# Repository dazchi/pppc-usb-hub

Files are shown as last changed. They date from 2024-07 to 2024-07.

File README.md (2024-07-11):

# Per-port Power Control USB HUB
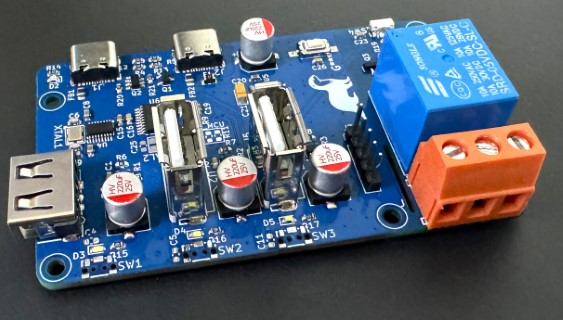
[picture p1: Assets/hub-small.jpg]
Preview


## Key Features
* 3-port USB hub fully compatiable with USB High-Speed(480Hz), Full-Speed(12Hz) and Low-Speed(1.5MHz) devices
* Supports per-port power control, current limitation and thermal shutdown protection
* No special driver required, reuses the driver from the widely known CH340 USB-to-serial chip
* Supports 5V 2A external USB-C power supply
* Reverse current protection along with resetable fuse
* Relay: SRD-05VDC-SL-C 10A 30VDC, 10A 250VAC
* Customized settings stored in built-in flash memory

## Schematic & Layout (Designed w/ KiCAD 8.0)
Schematic  
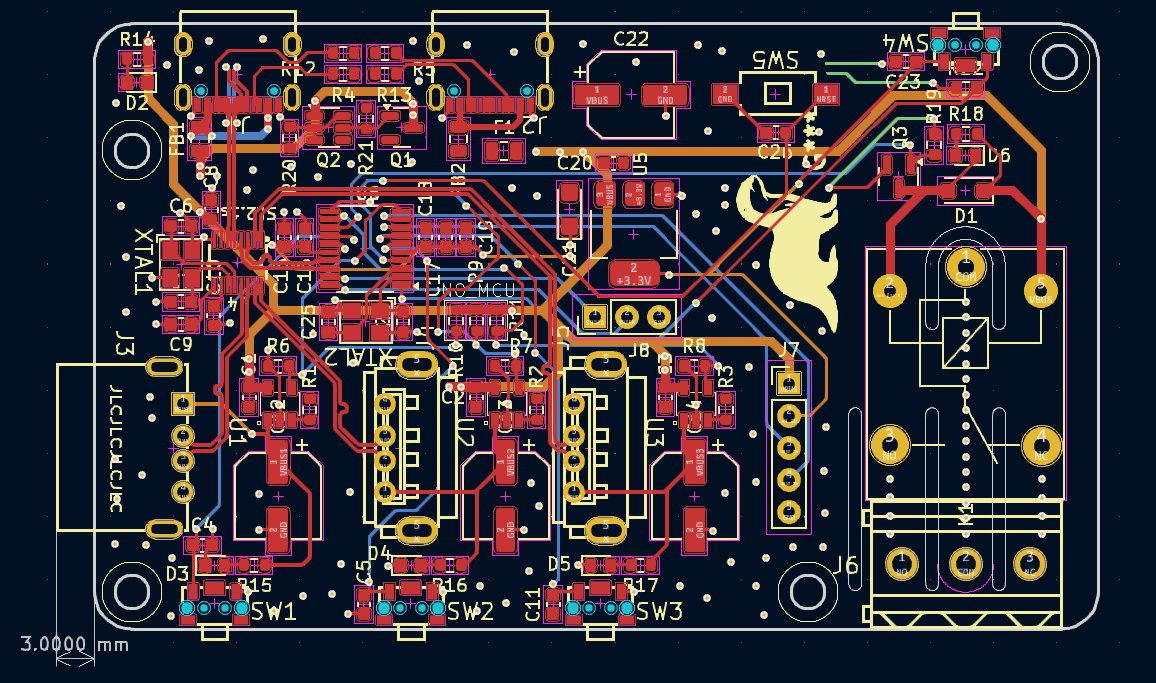
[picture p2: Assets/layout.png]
Schematic
  

## 3D Printed Case (Designed w/ Fusion 360)
3D Printed Case 

## Basic Control Commands (Group Control)
Turn On:  ```A0 01 01 A2```
  
Turn Off: ```A0 01 00 A1```
  
*These commands are designed to mimic the command of **[USB RELAY](https://www.smart-prototyping.com/USB-Relay-1-Channel)** on purpose*  
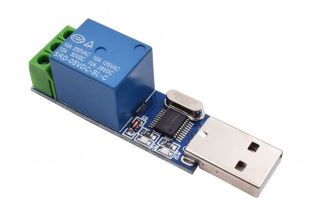
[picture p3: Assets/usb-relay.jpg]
USB RELAY
  

## Advanced Control Commands

### Per-port control
Foramt: ```F0 {AA} {BB} {ZZ} ```  

* ```{AA}``` Port Address:  
  | Port | Address |
  |:----:|:-------:|
  | USB1 |   0x01  |
  | USB2 |   0x02  |
  | USB3 |   0x03  |
  | Relay|   0x04  |

*  ```{BB}``` On/Off:  
    * ON: ```0x01```  
    * OFF: ```0x00```  

* ```{ZZ}``` Checksum:  
 ```ZZ = (0xF0 + {AA} + {BB}) & 0xFF```

Example:  
* Turn on USB1: ```F0 01 01 F2```  
* Turn off Relay: ```F0 04 00 F4```  

### Write Device Settings
Format:  
* Command: ```AB CD EF 67 {X1 X2 X3 X4} ZZ```:

    *  ```{X1 X2 X3 X4}``` Device Settings:  
        |          |                       |
        |:--------:|:---------------------:|
        | ```X1``` |   USB1 Port Settings  |
        | ```X2``` |   USB2 Port Settings  |
        | ```X3``` |   USB3 Port Settings  |
        | ```X4``` |  Relay Port Settings  |
        ```c
        typedef struct DeviceSettings
        {
            PortSettings_t usb1;
            PortSettings_t usb2;
            PortSettings_t usb3;
            PortSettings_t relay;
        } __attribute__((packed)) DeviceSettings_t;
        ```
        * Port Settings:  
            |  Bit Field |  Setting  |  Description |
            |:--------:|:---------------------:|:------------------|
            | b0 |   Port Default State  | Default state of port while power on  |
            | b1 |   *Group Control       | 0: Disable group control (ignores **Basic Control Commands**)<br>1: Enable group control
            | b2 |   *Polarity  | Polarity of the port during group control<br>0: Default polarity<br>1: Reversed polarity
            | b3 ~ b7 |  Reserved  |  Reserved for future use   |

            **The **Group Control** and the **Polarity** only affets the **Basic Control Commands***
            ```c
            typedef struct PortSettings
            {
                uint8_t defaultState :1;
                uint8_t groupControl :1;
                uint8_t polarity :1;
                uint8_t reserved :5;
            } __attribute__((packed)) PortSettings_t;
            ```
    * ```{ZZ}``` Checksum:  
    ```ZZ = (0xAB + 0xCD + 0xEF + 0x67 + {X1} {X2} {X3} {X4}) & 0xFF```

* Response:  
    ```SUCCESS``` or ```FAILED```

Example:  
* Defaut Devcie Settings  
    TX: ```AB CD EF 67 07 07 07 02 E5```  
    RX: ```SUCCESS```  

    This command sets the default state of USB1, USB2 and USB3 to On, the default state of Relay to Off.  
    The "Turn on" command ```A0 01 01 A2``` turns on the relay but turns off USB1, USB2 and USB3.  
    The "Turn off" command ```A0 01 00 A1``` turns off the relay but turns on USB1, USB2 and USB3.

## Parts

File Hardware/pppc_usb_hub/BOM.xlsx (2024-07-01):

Reference | Value | Datasheet | Footprint | Qty | DNP | MSRP | Total
C1,C2,C3,C4,C5,C11,C25 | 0.1uF | https://www.lcsc.com/product-detail/Multilayer-Ceramic-Capacitors-MLCC-SMD-SMT_Samsung-Electro-Mechanics-CL10B104KB8NNNC_C1591.html | Capacitor_SMD:C_0201_0603Metric | 7 |  | 0.0024 | 3.8712
C6,C7,C23,C24 | 20pF | https://www.lcsc.com/product-detail/Multilayer-Ceramic-Capacitors-MLCC-SMD-SMT_FH-Guangdong-Fenghua-Advanced-Tech-0603CG200F500NT_C165732.html | Capacitor_SMD:C_0201_0603Metric | 4 |  | 0.014
C8,C9,C10,C20 | 10uF | https://www.lcsc.com/product-detail/Multilayer-Ceramic-Capacitors-MLCC-SMD-SMT_Samsung-Electro-Mechanics-CL10A106MQ8NNNC_C1691.html | Capacitor_SMD:C_0201_0603Metric | 4 |  | 0.0044
C12,C13,C14,C22 | 220uF | https://www.lcsc.com/product-detail/Solid-Capacitors_Honor-Elec-HV1E227M0607PZ_C5246541.html | Capacitor_SMD:CP_Elec_6.3x7.7 | 4 |  | 0.1408
C15 | 4.7uF | https://www.lcsc.com/product-detail/Multilayer-Ceramic-Capacitors-MLCC-SMD-SMT_Samsung-Electro-Mechanics-CL10A475KQ8NNNC_C8032.html | Capacitor_SMD:C_0201_0603Metric | 1 |  | 0.0041
C16,C17 | 100nF | https://www.lcsc.com/product-detail/Multilayer-Ceramic-Capacitors-MLCC-SMD-SMT_Samsung-Electro-Mechanics-CL10B104KB8NNNC_C1591.html | Capacitor_SMD:C_0201_0603Metric | 2 |  | 0.0024
C18 | 10nF | https://www.lcsc.com/product-detail/Multilayer-Ceramic-Capacitors-MLCC-SMD-SMT_YAGEO-CC0603KRX7R9BB103_C100042.html | Capacitor_SMD:C_0201_0603Metric | 1 |  | 0.0019
C19 | 1uF | https://www.lcsc.com/product-detail/Multilayer-Ceramic-Capacitors-MLCC-SMD-SMT_Samsung-Electro-Mechanics-CL10A105KB8NNNC_C15849.html | Capacitor_SMD:C_0201_0603Metric | 1 |  | 0.0042
C21 | 22uF | https://www.lcsc.com/product-detail/Tantalum-Capacitors_KEMET-T491A226K006AT_C118989.html | Capacitor_Tantalum_SMD:CP_EIA-3216-10_Kemet-I | 1 |  | 0.0801
D1 | 1N4007 | https://www.lcsc.com/product-detail/Diodes-General-Purpose_MSKSEMI-1N4007-A7_C2902912.html | Diode_SMD:D_SOD-123F | 1 |  | 0.0038
D2 | POWER | https://www.lcsc.com/product-detail/Light-Emitting-Diodes-LED_XINGLIGHT-XL-1608UOC-06_C965800.html | LED_SMD:LED_0201_0603Metric | 1 |  | 0.0051
D3 | USB1 | https://www.lcsc.com/product-detail/Light-Emitting-Diodes-LED_XINGLIGHT-XL-1608UWC-04_C965808.html | LED_SMD:LED_0201_0603Metric | 1 |  | 0.0053
D4 | USB2 | https://www.lcsc.com/product-detail/Light-Emitting-Diodes-LED_XINGLIGHT-XL-1608UWC-04_C965808.html | LED_SMD:LED_0201_0603Metric | 1 |  | 0.0053
D5 | USB3 | https://www.lcsc.com/product-detail/Light-Emitting-Diodes-LED_XINGLIGHT-XL-1608UWC-04_C965808.html | LED_SMD:LED_0201_0603Metric | 1 |  | 0.0053
D6 | RELAY | https://www.lcsc.com/product-detail/Light-Emitting-Diodes-LED_XINGLIGHT-XL-1608UWC-04_C965808.html | LED_SMD:LED_0201_0603Metric | 1 |  | 0.0053
F1 | Polyfuse | https://www.lcsc.com/product-detail/Resettable-Fuses_LUTE-0805L125-6NR_C7499987.html | Capacitor_SMD:C_0805_2012Metric | 1 |  | 0.0584
FB1,FB2 | BLM21PG221SN1D | https://www.lcsc.com/product-detail/Ferrite-Beads_Murata-Electronics-BLM21PG221SN1D_C85840.html | Fuse:Fuse_0805_2012Metric | 2 |  | 0.0148
J1,J2 | USB_C_Signal | https://www.lcsc.com/product-detail/USB-Connectors_SHOU-HAN-TYPE-C-16PIN-2MD-073_C2765186.html | PCBLIB_USB-C-SMD_TYPE-C-6PIN-2MD-073_2024-05-18:USB-C-SMD_TYPE-C-6PIN-2MD-073 | 2 |  | 0.0501
J3 | USB_A_1 | https://www.lcsc.com/product-detail/USB-Connectors_SHOU-HAN-AF-10-0-HC6-3_C456017.html | PCBLIB_USB-A-TH_AF-10.0-HC6.3_2024-05-20:USB-A-TH_AF-10.0-HC6.3 | 1 |  | 0.0362
J4 | USB_A_2 | https://www.lcsc.com/product-detail/USB-Connectors_Ckmtw-Shenzhen-Cankemeng-U-USBAS04P-F001_C386737.html | PCBLIB_USB-A-TH_USB-M-22_2024-05-19:USB-A-TH_USB-M-22 | 1 |  | 0.1504
J5 | USB_A_3 | https://www.lcsc.com/product-detail/USB-Connectors_Ckmtw-Shenzhen-Cankemeng-U-USBAS04P-F001_C386737.html | PCBLIB_USB-A-TH_USB-M-22_2024-05-19:USB-A-TH_USB-M-22 | 1 |  | 0.1504
J6 | Con_Relay | https://www.lcsc.com/product-detail/Screw-terminal_DORABO-DB128L-5-08-3P-OG-S_C430604.html | PCBLIB_CONN-TH_3P-P5.08_DB128L-5.08-3P-OG-S_2024-05-19:CONN-TH_3P-P5.08_DB128L-5.08-3P-OG-S | 1 |  | 0.1801
J7 | Conn_UART | https://www.lcsc.com/product-detail/Pin-Headers_Hanbo-Electronic-HB-PH3-25415PB2GOP_C6332198.html | Connector_PinHeader_2.54mm:PinHeader_1x05_P2.54mm_Vertical | 1 |  | 0.0223
J8 | Conn_Debug | ~ | Connector_PinHeader_2.54mm:PinHeader_1x03_P2.54mm_Vertical | 1
K1 | Relay | https://www.lcsc.com/product-detail/Power-Relays_Ningbo-Songle-Relay-SRD-05VDC-SL-C_C35449.html | Relay_THT:Relay_SPDT_SANYOU_SRD_Series_Form_C | 1 |  | 0.3124
Q1 | DMG2305UX | https://www.lcsc.com/product-detail/MOSFETs_TECH-PUBLIC-DMG2305UX_C2940629.html | Package_TO_SOT_SMD:SOT-23 | 1 |  | 0.0517
Q2 | DMMT5401 | https://www.lcsc.com/product-detail/Bipolar-Transistors-BJT_Diodes-Incorporated-DMMT5401-7-F_C154733.html | Package_TO_SOT_SMD:SOT-23-6 | 1 |  | 0.1683
Q3 | AO3400A | https://www.lcsc.com/product-detail/MOSFETs_UMW-Youtai-Semiconductor-Co-Ltd-AO3400A_C347475.html | Package_TO_SOT_SMD:SOT-23 | 1 |  | 0.0278
R1,R2,R3 | 4.53k | https://www.lcsc.com/product-detail/Chip-Resistor-Surface-Mount_FH-Guangdong-Fenghua-Advanced-Tech-RS-03K4531FT_C321916.html | Resistor_SMD:R_0201_0603Metric | 3 |  | 0.0012
R4,R5,R12,R13 | 5.1k | https://www.lcsc.com/product-detail/Chip-Resistor-Surface-Mount_UNI-ROYAL-Uniroyal-Elec-0603WAF5101T5E_C23186.html | Resistor_SMD:R_0201_0603Metric | 4 |  | 0.0010
R6,R7,R8,R19,R20,R22 | 10k | https://www.lcsc.com/product-detail/Chip-Resistor-Surface-Mount_UNI-ROYAL-Uniroyal-Elec-0603WAF1002T5E_C25804.html | Resistor_SMD:R_0201_0603Metric | 6 |  | 0.0009
R9,R10,R11 | 0R | ~ | Resistor_SMD:R_0201_0603Metric | 3
R14,R15,R16,R17,R18 | 330 | https://www.lcsc.com/product-detail/Chip-Resistor-Surface-Mount_UNI-ROYAL-Uniroyal-Elec-0603WAF3300T5E_C23138.html | Resistor_SMD:R_0201_0603Metric | 5 |  | 0.001
R21 | 47k | https://www.lcsc.com/product-detail/Chip-Resistor-Surface-Mount_UNI-ROYAL-Uniroyal-Elec-0603WAF4701T5E_C23162.html | Resistor_SMD:R_0201_0603Metric | 1 |  | 0.001
SW1 | USB1 | https://www.lcsc.com/product-detail/Tactile-Switches_G-Switch-GT-TC020B-H035-L05_C17179534.html | PCBLIB_SW-SMD_GT-TC020B-H035-L05_2024-05-21:SW-SMD_GT-TC020B-H035-L05 | 1 |  | 0.0726
SW2 | USB2 | https://www.lcsc.com/product-detail/Tactile-Switches_G-Switch-GT-TC020B-H035-L05_C17179534.html | PCBLIB_SW-SMD_GT-TC020B-H035-L05_2024-05-21:SW-SMD_GT-TC020B-H035-L05 | 1 |  | 0.0726
SW3 | USB3 | https://www.lcsc.com/product-detail/Tactile-Switches_G-Switch-GT-TC020B-H035-L05_C17179534.html | PCBLIB_SW-SMD_GT-TC020B-H035-L05_2024-05-21:SW-SMD_GT-TC020B-H035-L05 | 1 |  | 0.0726
SW4 | BOOT0 | https://www.lcsc.com/product-detail/Tactile-Switches_XKB-Connection-TS-1101-C-W_C318938.html | PCBLIB_SW-SMD_L6.0-W3.3-LS8.0_2024-05-19:SW-SMD_L6.0-W3.3-LS8.0 | 1 |  | 0.0323
SW5 | RESET | https://www.lcsc.com/product-detail/Tactile-Switches_XKB-Connection-TS-1101-C-W_C318938.html | PCBLIB_SW-SMD_L6.0-W3.3-LS8.0_2024-05-19:SW-SMD_L6.0-W3.3-LS8.0 | 1 |  | 0.0323
U1,U2,U3 | MT9700 | https://www.lcsc.com/product-detail/span-style-background-color-ff0-Power-span-Distribution-Switches_XI-AN-Aerosemi-Tech-MT9700_C89855.html | PCBLIB_SOT-23-5_L3.0-W1.7-P0.95-LS2.8-BR_2024-05-18:SOT-23-5_L3.0-W1.7-P0.95-LS2.8-BR | 3 |  | 0.0356
U4 | SL2.1s | https://www.lcsc.com/product-detail/USB-Converters_CoreChips-SL2-1s_C2684433.html | PCB_NEW_PCB_2024-05-14:SSOP-16_L4.6-W2.6-P0.53-LS4.0-BL | 1 |  | 0.205
U5 | AMS1117-3.3 | https://www.lcsc.com/product-detail/Linear-Voltage-Regulators-LDO_Advanced-Monolithic-Systems-AMS1117-3-3_C6186.html | Package_TO_SOT_SMD:SOT-223-3_TabPin2 | 1 |  | 0.1298
U6 | STM32F042F6Px | https://www.lcsc.com/product-detail/Microcontroller-Units-MCUs-MPUs-SOCs_STMicroelectronics-STM32F042F6P6TR_C2969989.html | Package_SO:TSSOP-20_4.4x6.5mm_P0.65mm | 1 |  | 1.1458
XTAL1,XTAL2 | 12MHz | https://www.lcsc.com/product-detail/Crystals_YXC-X322512MSB4SI_C9002.html | PCBLIB_OSC-SMD_4P-L3.2-W2.5-BL_2024-05-18:OSC-SMD_4P-L3.2-W2.5-BL | 2 |  | 0.0571

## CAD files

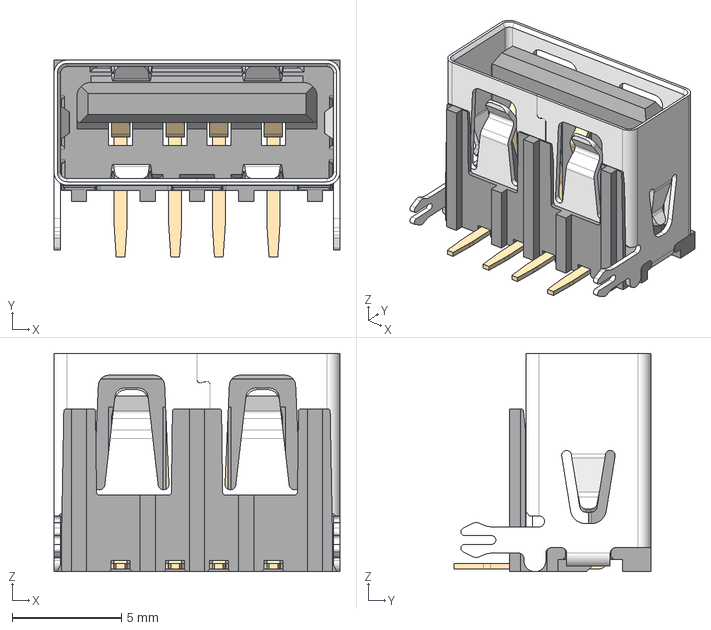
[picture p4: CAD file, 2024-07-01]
Hardware/3d_models/usb1125-gf-b.stp
13.1 x 9.01 x 10.0 mm

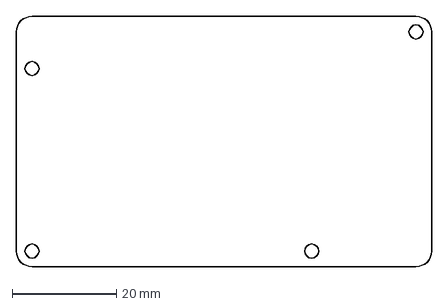
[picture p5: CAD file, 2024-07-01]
Hardware/PCB_Outline.dxf
79.6 x 48.0 mm

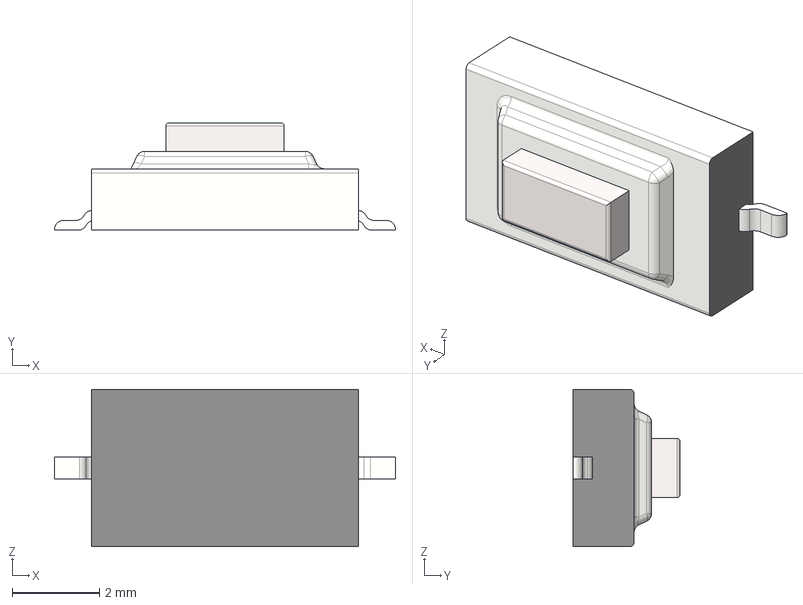
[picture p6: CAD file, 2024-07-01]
Hardware/3d_models/TactileButton(6x3,5mm)_SMD.stp
7.80 x 2.45 x 3.60 mm

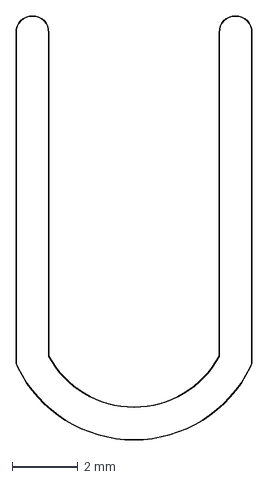
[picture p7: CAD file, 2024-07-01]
Hardware/SLOT.dxf
7.20 x 12.9 mm

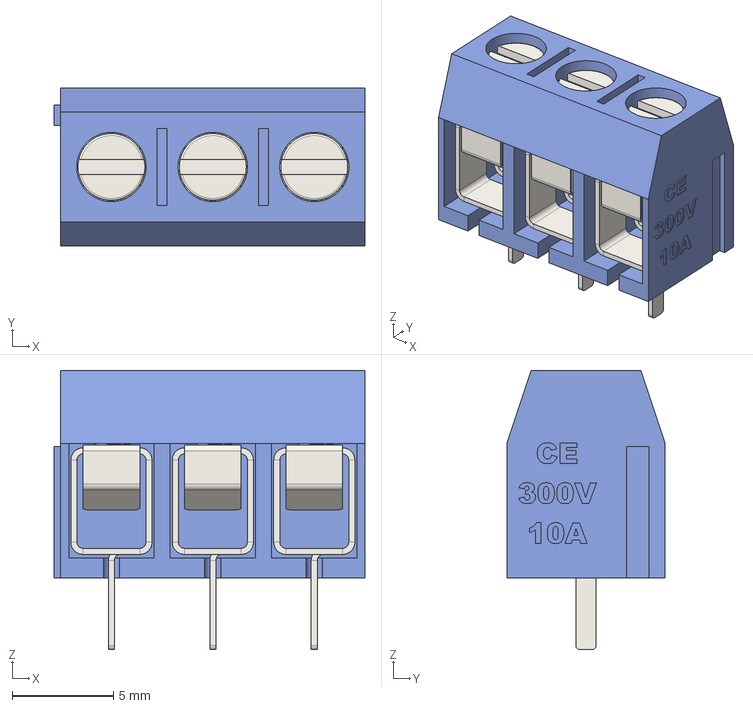
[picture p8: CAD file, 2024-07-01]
Hardware/3d_models/dg-301-5_0.step
15.3 x 7.80 x 13.8 mm

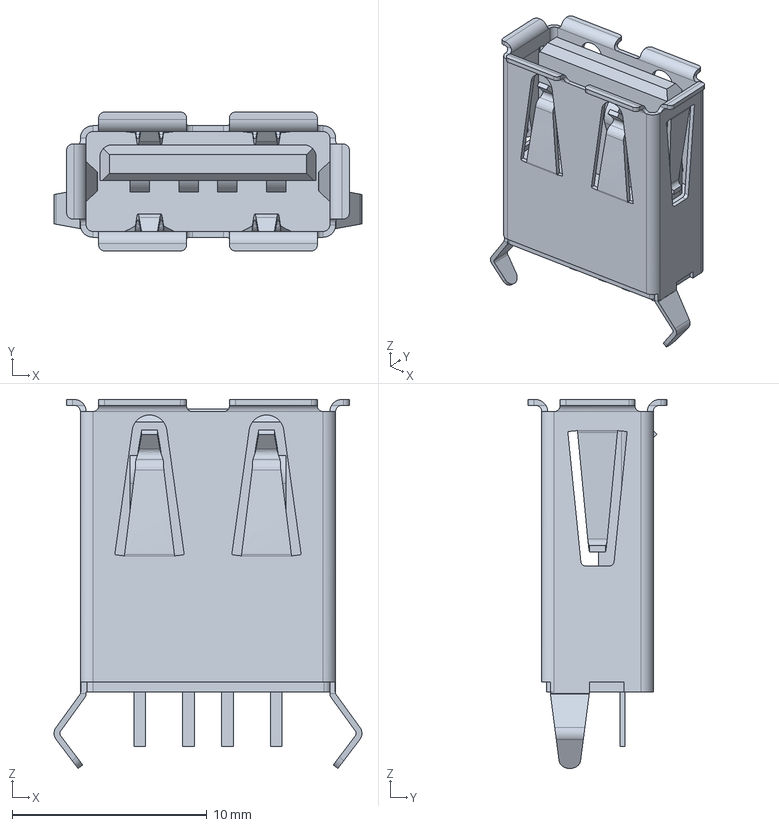
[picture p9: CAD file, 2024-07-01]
Hardware/3d_models/USB-A-S-F-B-VT.stp
15.8 x 7.12 x 18.9 mm

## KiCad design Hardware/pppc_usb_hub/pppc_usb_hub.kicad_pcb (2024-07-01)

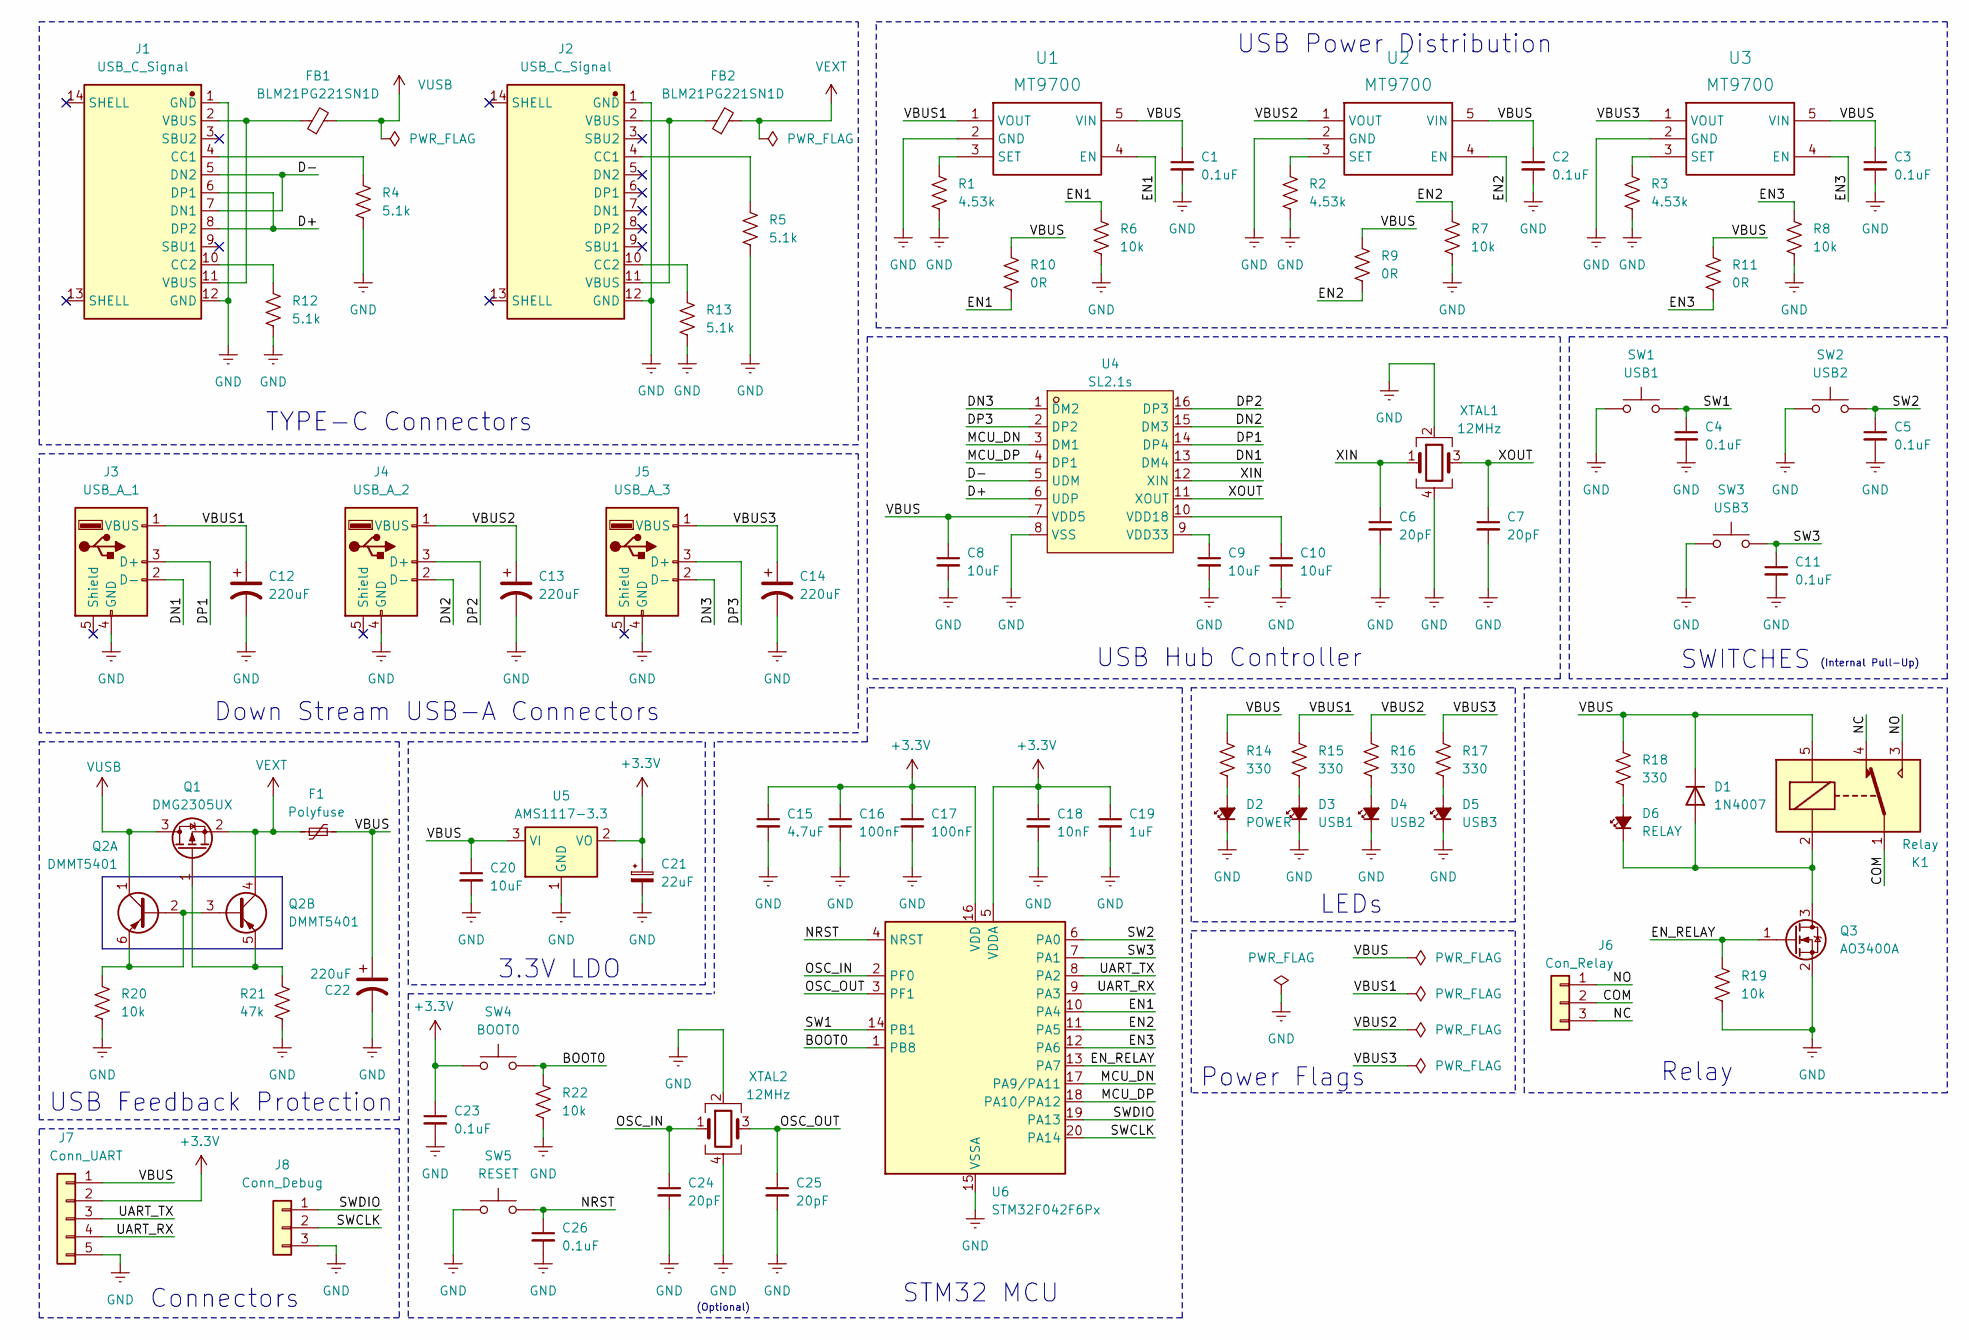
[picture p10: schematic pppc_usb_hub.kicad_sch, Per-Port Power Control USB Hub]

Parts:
C1, C2, C3, C4, C5, C11, C23, C26: 0.1uF; C_0603_1608Metric
C6, C7, C24, C25: 20pF; C_0603_1608Metric
C8, C9, C10, C20: 10uF; C_0603_1608Metric
C12, C13, C14, C22: 220uF; CP_Elec_6.3x7.7
C15: 4.7uF; C_0603_1608Metric
C16, C17: 100nF; C_0603_1608Metric
C18: 10nF; C_0603_1608Metric
C19: 1uF; C_0603_1608Metric
C21: 22uF; CP_EIA-3216-10_Kemet-I
D1: 1N4007; D_SOD-123F
D2: POWER; LED_0603_1608Metric
D3: USB1; LED_0603_1608Metric
D4: USB2; LED_0603_1608Metric
D5: USB3; LED_0603_1608Metric
D6: RELAY; LED_0603_1608Metric
F1: Polyfuse; C_0805_2012Metric
FB1, FB2: BLM21PG221SN1D; Fuse_0805_2012Metric
J1, J2: USB_C_Signal; USB-C-SMD_TYPE-C-6PIN-2MD-073
J3: USB_A_1; USB-A-TH_AF-10.0-HC6.3
J4: USB_A_2; USB-A-TH_USB-M-22
J5: USB_A_3; USB-A-TH_USB-M-22
J6: Con_Relay; CONN-TH_3P-P5.08_DB128L-5.08-3P-OG-S
J7: Conn_UART; PinHeader_1x05_P2.54mm_Vertical
J8: Conn_Debug; PinHeader_1x03_P2.54mm_Vertical
K1: Relay; Relay_SPDT_SANYOU_SRD_Series_Form_C
Q1: DMG2305UX; SOT-23
Q2: DMMT5401; SOT-23-6
Q3: AO3400A; SOT-23
R1, R2, R3: 4.53k; R_0603_1608Metric
R4, R5, R12, R13: 5.1k; R_0603_1608Metric
R6, R7, R8, R19, R20, R22: 10k; R_0603_1608Metric
R9, R10, R11: 0R; R_0603_1608Metric
R14, R15, R16, R17, R18: 330; R_0603_1608Metric
R21: 47k; R_0603_1608Metric
SW1: USB1; SW-SMD_GT-TC020B-H035-L05
SW2: USB2; SW-SMD_GT-TC020B-H035-L05
SW3: USB3; SW-SMD_GT-TC020B-H035-L05
SW4: BOOT0; SW-SMD_GT-TC020B-H035-L05
SW5: RESET; SW-SMD_L6.0-W3.3-LS8.0
U1, U2, U3: MT9700; SOT-23-5_L3.0-W1.7-P0.95-LS2.8-BR
U4: SL2.1s; SSOP-16_L4.6-W2.6-P0.53-LS4.0-BL
U5: AMS1117-3.3; SOT-223-3_TabPin2
U6: STM32F042F6Px; TSSOP-20_4.4x6.5mm_P0.65mm
XTAL1, XTAL2: 12MHz; OSC-SMD_4P-L3.2-W2.5-BL

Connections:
+3.3V: C15.1, C16.1, C17.1, C18.1, C19.1, C21.1, C23.1, J7.2, SW4.2, U5.2 (VO), U6.5 (VDDA), U6.16 (VDD)
/BOOT0: R22.1, SW4.1, U6.1 (PB8)
/COM: J6.2, K1.1
/D+: J1.6 (DP1), J1.8 (DP2), U4.6 (UDP)
/D-: J1.5 (DN2), J1.7 (DN1), U4.5 (UDM)
/DN1: J3.2 (D-), U4.13 (DM4)
/DN2: J4.2 (D-), U4.15 (DM3)
/DN3: J5.2 (D-), U4.1 (DM2)
/DP1: J3.3 (D+), U4.14 (DP4)
/DP2: J4.3 (D+), U4.16 (DP3)
/DP3: J5.3 (D+), U4.2 (DP2)
/EN1: R6.1, R10.2, U1.4 (EN), U6.10 (PA4)
/EN2: R7.1, R9.2, U2.4 (EN), U6.11 (PA5)
/EN3: R8.1, R11.2, U3.4 (EN), U6.12 (PA6)
/EN_RELAY: Q3.1 (G), R19.1, U6.13 (PA7)
/MCU_DN: U4.3 (DM1), U6.17 (PA9/PA11)
/MCU_DP: U4.4 (DP1), U6.18 (PA10/PA12)
/NC: J6.3, K1.4
/NO: J6.1, K1.3
/NRST: C26.1, SW5.1, U6.4 (NRST)
/OSC_IN: C24.1, U6.2 (PF0), XTAL2.1
/OSC_OUT: C25.1, U6.3 (PF1), XTAL2.3
/SW1: C4.1, SW1.1, U6.14 (PB1)
/SW2: C5.1, SW2.1, U6.6 (PA0)
/SW3: C11.1, SW3.1, U6.7 (PA1)
/SWCLK: J8.2, U6.20 (PA14)
/SWDIO: J8.1, U6.19 (PA13)
/UART_RX: J7.4, U6.9 (PA3)
/UART_TX: J7.3, U6.8 (PA2)
/VBUS: C1.1, C2.1, C3.1, C8.1, C20.1, C22.1, D1.1 (K), F1.2, J7.1, K1.5, R9.1, R10.1, R11.1, R14.1, R18.1, U1.5 (VIN), U2.5 (VIN), U3.5 (VIN), U4.7 (VDD5), U5.3 (VI)
/VBUS1: C12.1, J3.1 (VBUS), R15.1, U1.1 (VOUT)
/VBUS2: C13.1, J4.1 (VBUS), R16.1, U2.1 (VOUT)
/VBUS3: C14.1, J5.1 (VBUS), R17.1, U3.1 (VOUT)
/XIN: C6.1, U4.12 (XIN), XTAL1.1
/XOUT: C7.1, U4.11 (XOUT), XTAL1.3
GND: C1.2, C2.2, C3.2, C4.2, C5.2, C6.2, C7.2, C8.2, C9.2, C10.2, C11.2, C12.2, C13.2, C14.2, C15.2, C16.2, C17.2, C18.2, C19.2, C20.2, C21.2, C22.2, C23.2, C24.2, C25.2, C26.2, D2.1 (K), D3.1 (K), D4.1 (K), D5.1 (K), J1.1 (GND), J1.12 (GND), J2.1 (GND), J2.12 (GND), J3.4 (GND), J4.4 (GND), J5.4 (GND), J7.5, J8.3, Q3.2 (S), R1.2, R2.2, R3.2, R4.2, R5.2, R6.2, R7.2, R8.2, R12.2, R13.2, R19.2, R20.2, R21.2, R22.2, SW1.2, SW2.2, SW3.2, SW5.2, U1.2 (GND), U2.2 (GND), U3.2 (GND), U4.8 (VSS), U5.1 (GND), U6.15 (VSSA), XTAL1.2, XTAL1.4, XTAL2.2, XTAL2.4
unnamed: D1.2 (A), D6.1 (K), K1.2, Q3.3 (D)
unnamed: D2.2 (A), R14.2
unnamed: D3.2 (A), R15.2
unnamed: D4.2 (A), R16.2
unnamed: D5.2 (A), R17.2
unnamed: D6.2 (A), R18.2
unnamed: FB1.1, J1.2 (VBUS), J1.11 (VBUS)
unnamed: FB2.1, J2.2 (VBUS), J2.11 (VBUS)
unnamed: J1.4 (CC1), R4.1
unnamed: J1.10 (CC2), R12.1
unnamed: J2.4 (CC1), R5.1
unnamed: J2.10 (CC2), R13.1
unnamed: Q1.1 (G), Q2.5 (E2), R21.1
unnamed: Q2.2 (B1), Q2.3 (B2), Q2.6 (E1), R20.1
unnamed: R1.1, U1.3 (SET)
unnamed: R2.1, U2.3 (SET)
unnamed: R3.1, U3.3 (SET)
unnamed: C10.1, U4.10 (VDD18)
unnamed: C9.1, U4.9 (VDD33)
VEXT: F1.1, FB2.2, Q1.2 (S), Q2.4 (C2)
VUSB: FB1.2, Q1.3 (D), Q2.1 (C1)

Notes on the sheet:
3.3V LDO
Relay
Connectors
(Internal Pull-Up)
Power Flags
(Optional)
LEDs
TYPE-C Connectors
STM32 MCU
USB Hub Controller
Down Stream USB-A Connectors
USB Power Distribution
SWITCHES
USB Feedback Protection

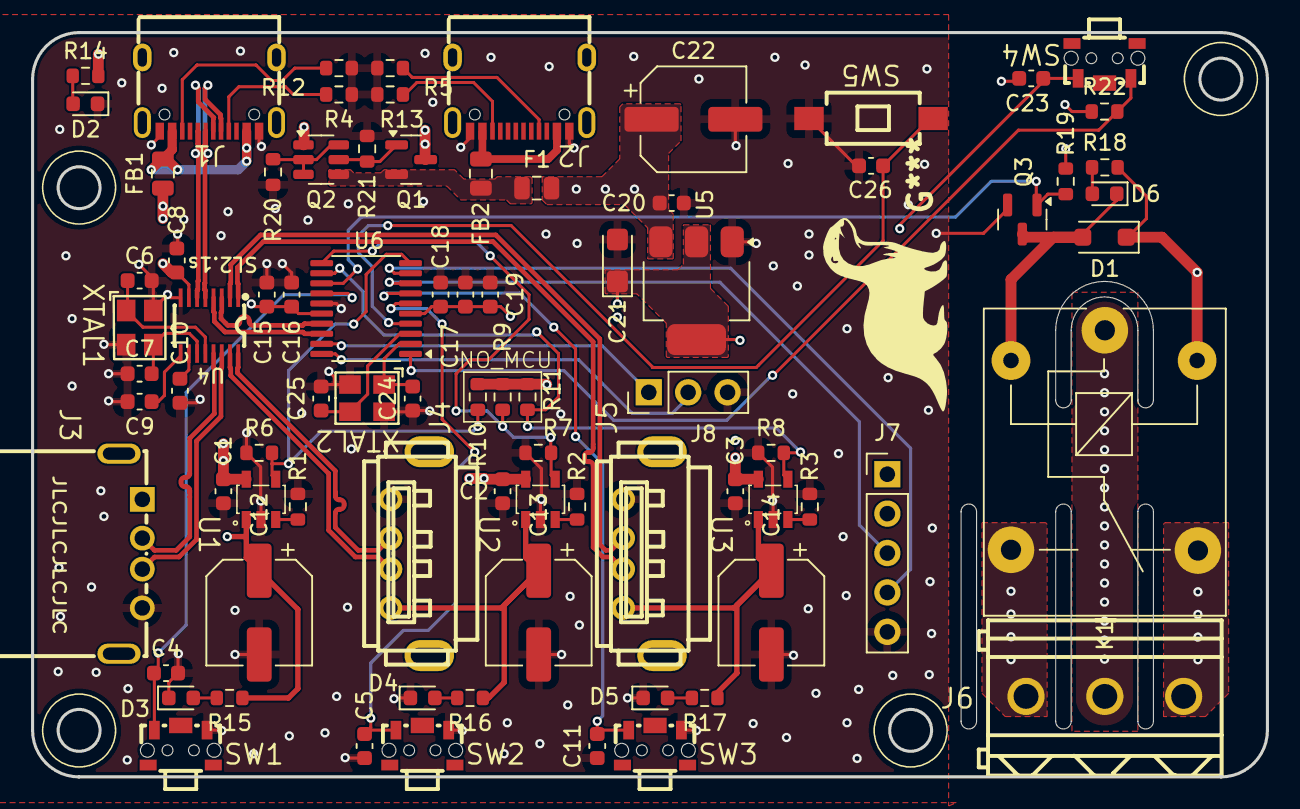
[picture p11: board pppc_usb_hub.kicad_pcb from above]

Board: 4 copper layers, 79.6 x 48.0 mm, 82 parts (0 on the bottom side), 57 nets.

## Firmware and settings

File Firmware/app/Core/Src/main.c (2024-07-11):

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
/* Includes ------------------------------------------------------------------*/
#include "main.h"
#include "dma.h"
#include "tim.h"
#include "usart.h"
#include "usb_device.h"
#include "gpio.h"

/* USER CODE BEGIN Includes */
#include "usbd_cdc_if.h"
/* USER CODE END Includes */

/* USER CODE BEGIN PTD */

typedef struct PortSettings {
	uint8_t defaultState :1;
	uint8_t groupControl :1;
	uint8_t polarity :1;
	uint8_t reserved :5;
} __attribute__((packed)) PortSettings_t;

typedef struct DeviceSettings {
	PortSettings_t usb1;
	PortSettings_t usb2;
	PortSettings_t usb3;
	PortSettings_t relay;
} __attribute__((packed)) DeviceSettings_t;

typedef struct Command {
	union{
		uint32_t raw;
		struct{
			uint8_t header;
			uint8_t addr;
			uint8_t state;
			uint8_t checksum;
		};
	};

} __attribute__((packed)) Command_t;

typedef struct CommandExtended {
	Command_t command;
	DeviceSettings_t settings;
	uint8_t checksum;
} __attribute__((packed)) CommandExtended_t;
/* USER CODE END PTD */


/* USER CODE BEGIN PV */
extern TIM_HandleTypeDef htim3;
uint8_t cdcRxBuf[64] = { 0 };
uint8_t cdcTxBuf[8] = { 0 };
uint8_t rxLen = 0;
volatile uint8_t rxDone = 0;
uint8_t portCtrlState = 0;
uint8_t portCtrlFlag = 0x00;

__attribute__((section(".persist_data"))) DeviceSettings_t Settings = {
		.usb1 =		{ .defaultState = 1, .groupControl = 1, .polarity = 1 },
		.usb2 = 	{ .defaultState = 1, .groupControl = 1, .polarity = 1 },
		.usb3 = 	{ .defaultState = 1, .groupControl = 1, .polarity = 1 },
		.relay = 	{ .defaultState = 0, .groupControl = 1, .polarity = 0 },
};
/* USER CODE END PV */

void SystemClock_Config(void);
/* USER CODE BEGIN PFP */
extern void FLASH_PageErase(uint32_t PageAddress);
void Initialize_Ports();
void Enable_All_Ports();
void Disable_All_Ports();
uint8_t Calculate_Checksum(void* data, uint8_t len);
void Process_Rx();
uint8_t Save_Settings(DeviceSettings_t* newSettings);
/* USER CODE END PFP */

/**
  * @brief  The application entry point.
  * @retval int
  */
int main(void)
{

  /* MCU Configuration--------------------------------------------------------*/

  /* Reset of all peripherals, Initializes the Flash interface and the Systick. */
  HAL_Init();

  /* Configure the system clock */
  SystemClock_Config();

  /* Initialize all configured peripherals */
  MX_GPIO_Init();
  MX_DMA_Init();
  MX_USART2_UART_Init();
  MX_USB_DEVICE_Init();
  MX_TIM3_Init();
  /* USER CODE BEGIN 2 */
  HAL_TIM_Base_Start_IT(&htim3);
  Initialize_Ports();
  /* USER CODE END 2 */

  /* Infinite loop */
  /* USER CODE BEGIN WHILE */

	while (1) {
		if(rxDone){
			Process_Rx();
		}

    /* USER CODE END WHILE */

    /* USER CODE BEGIN 3 */
	}
  /* USER CODE END 3 */
}

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
/* USER CODE BEGIN 4 */

void Initialize_Ports()
{
	portCtrlFlag = 0xF1;
	portCtrlState = 0x01;
}

void Enable_All_Ports() {

	portCtrlFlag = 0x11;
	portCtrlState = 0x01;
}

void Disable_All_Ports() {

	portCtrlFlag = 0x01;
	portCtrlState = 0x00;
}

void Port_Ctrl_Handler() {
	static uint8_t cooldown = 0;

	if (HAL_GPIO_ReadPin(GPIOB, GPIO_PIN_8) && (cooldown == 0)) {
		if (portCtrlState) {
			Disable_All_Ports();
		} else {
			Enable_All_Ports();
		}
		cooldown = 10;
	}

	switch (portCtrlFlag) {
	case 0x01:
		if(Settings.usb1.groupControl){
			HAL_GPIO_WritePin(GPIOA, USB1_EN_PIN, ~Settings.usb1.polarity & 0x1);
		}
		portCtrlFlag += 1;
		break;
	case 0x02:
		if(Settings.usb2.groupControl){
			HAL_GPIO_WritePin(GPIOA, USB2_EN_PIN, ~Settings.usb2.polarity & 0x1);
		}
		portCtrlFlag += 1;
		break;
	case 0x03:
		if(Settings.usb3.groupControl){
			HAL_GPIO_WritePin(GPIOA, USB3_EN_PIN, ~Settings.usb3.polarity & 0x1);
		}
		portCtrlFlag += 1;
		break;
	case 0x04:
		if(Settings.relay.groupControl){
			HAL_GPIO_WritePin(GPIOA, RELAY_EN_PIN, ~Settings.relay.polarity & 0x1);
		}
		portCtrlFlag = 0x00;
		break;
	case 0x11:
		if(Settings.usb1.groupControl){
			HAL_GPIO_WritePin(GPIOA, USB1_EN_PIN, Settings.usb1.polarity & 0x1);
		}
		portCtrlFlag += 1;
		break;
	case 0x12:
		if(Settings.usb2.groupControl){
			HAL_GPIO_WritePin(GPIOA, USB2_EN_PIN, Settings.usb2.polarity & 0x1);
		}
		portCtrlFlag += 1;
		break;
	case 0x13:
		if(Settings.usb3.groupControl){
			HAL_GPIO_WritePin(GPIOA, USB3_EN_PIN, Settings.usb3.polarity & 0x1);
		}
		portCtrlFlag += 1;
		break;
	case 0x14:
		if(Settings.relay.groupControl){
			HAL_GPIO_WritePin(GPIOA, RELAY_EN_PIN, Settings.relay.polarity & 0x1);
		}
		portCtrlFlag = 0x00;
		break;
	case 0xF1:
		HAL_GPIO_WritePin(GPIOA, USB1_EN_PIN, Settings.usb1.defaultState);
		portCtrlFlag += 1;
		break;
	case 0xF2:
		HAL_GPIO_WritePin(GPIOA, USB2_EN_PIN, Settings.usb2.defaultState);
		portCtrlFlag += 1;
		break;
	case 0xF3:
		HAL_GPIO_WritePin(GPIOA, USB3_EN_PIN, Settings.usb3.defaultState);
		portCtrlFlag += 1;
		break;
	case 0xF4:
		HAL_GPIO_WritePin(GPIOA, RELAY_EN_PIN, Settings.relay.defaultState);
		portCtrlFlag = 0x00;
		break;
	default:
		portCtrlFlag = 0x00;
		break;
	}

	cooldown -= cooldown ? 1 : 0;
}

void Process_Rx()
{
	Command_t *cmd;
	CommandExtended_t *cmdExt;

	cmd = (Command_t*)cdcRxBuf;

	if(cmd->checksum == Calculate_Checksum(cmd, sizeof(*cmd)-1))
	{
		switch(cmd->raw){
		case 0xA20101A0:
			Disable_All_Ports();
			break;
		case 0xA10001A0:
			Enable_All_Ports();
			break;
		case 0x67EFCDAB:
			cmdExt = (CommandExtended_t*)cdcRxBuf;

			if(cmdExt->checksum == Calculate_Checksum(cmdExt, sizeof(*cmdExt)-1))
			{
				uint8_t result = Save_Settings(&cmdExt->settings);

				if(result)
				{
					CDC_Transmit_FS("SUCCESS\n", 8);
				}else
				{
					CDC_Transmit_FS("FAILED\n", 7);
				}
				break;
			}
			break;
		case 0xFDFFFFFF:
			cdcTxBuf[0] = HAL_GPIO_ReadPin(GPIOA, RELAY_EN_PIN);
			cdcTxBuf[0] <<= 1;
			cdcTxBuf[0] |= HAL_GPIO_ReadPin(GPIOA, USB3_EN_PIN);
			cdcTxBuf[0] <<= 1;
			cdcTxBuf[0] |= HAL_GPIO_ReadPin(GPIOA, USB2_EN_PIN);
			cdcTxBuf[0] <<= 1;
			cdcTxBuf[0] |= HAL_GPIO_ReadPin(GPIOA, USB1_EN_PIN);

			memcpy(cdcTxBuf+1,&Settings,sizeof(Settings));

			CDC_Transmit_FS(cdcTxBuf, sizeof(Settings)+1);
			break;
		default:
			if(cmd->header == 0xF0)
			{
				switch(cmd->addr){
				case 0x01:
					HAL_GPIO_WritePin(GPIOA, USB1_EN_PIN, cmd->state & 0x1);
					break;
				case 0x02:
					HAL_GPIO_WritePin(GPIOA, USB2_EN_PIN, cmd->state & 0x1);
					break;
				case 0x03:
					HAL_GPIO_WritePin(GPIOA, USB3_EN_PIN, cmd->state & 0x1);
					break;
				case 0x04:
					HAL_GPIO_WritePin(GPIOA, RELAY_EN_PIN, cmd->state & 0x1);
					break;
				default:
					break;
				}
			}
			break;
		}
	}

	memset(cdcRxBuf, 0, 64);
	rxDone = 0;
}

uint8_t Calculate_Checksum(void* data, uint8_t len){
	uint8_t i = 0;
	uint8_t sum = 0;

	do
	{
		sum += ((uint8_t*)data)[i];
		i++;
	}while(i<len);

	return sum;
}


uint8_t Save_Settings(DeviceSettings_t* newSettings){
	static FLASH_EraseInitTypeDef EraseInitStruct;
	uint32_t PAGEError;
	HAL_StatusTypeDef status = HAL_OK;

	EraseInitStruct.TypeErase   = FLASH_TYPEERASE_PAGES;
    EraseInitStruct.PageAddress = (uint32_t)&Settings;
    EraseInitStruct.NbPages    	= 1;

	HAL_FLASH_Unlock();
	status = HAL_FLASHEx_Erase(&EraseInitStruct, &PAGEError);

	if(status != HAL_OK)
	{
		HAL_FLASH_Lock();
		return 0;
	}
	status = HAL_FLASH_Program(FLASH_TYPEPROGRAM_WORD, (uint32_t)&Settings, *((uint32_t*)newSettings));

	if(status != HAL_OK)
	{
		HAL_FLASH_Lock();
		return 0;
	}

	HAL_FLASH_Lock();

	return 1;
}

/* USER CODE END 4 */
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


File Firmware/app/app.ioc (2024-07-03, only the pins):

Mcu.UserName=STM32F042F6Px
PA0.Signal=GPIO_Input
PA1.Signal=GPIO_Input
PA11.Signal=USB_DM
PA12.Signal=USB_DP
PA13.Signal=SYS_SWDIO
PA14.Signal=SYS_SWCLK
PA2.Signal=USART2_TX
PA3.Signal=USART2_RX
PA4.Signal=GPIO_Output
PA5.Signal=GPIO_Output
PA6.Signal=GPIO_Output
PA7.Signal=GPIO_Output
PB1.Signal=GPIO_Input
PB8.Signal=GPIO_Input

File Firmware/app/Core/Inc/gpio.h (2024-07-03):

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
/* Define to prevent recursive inclusion -------------------------------------*/
#ifndef __GPIO_H__
#define __GPIO_H__

#ifdef __cplusplus
extern "C" {
#endif

/* Includes ------------------------------------------------------------------*/
#include "main.h"

/* USER CODE BEGIN Private defines */
#define USB1_EN_PIN GPIO_PIN_4
#define USB2_EN_PIN GPIO_PIN_5
#define USB3_EN_PIN GPIO_PIN_6
#define RELAY_EN_PIN GPIO_PIN_7

/* USER CODE END Private defines */

void MX_GPIO_Init(void);

#ifdef __cplusplus
}
#endif
#endif /*__ GPIO_H__ */

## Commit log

2024-07-01 Add README.md and delete unnecessary files
    [pppc_usb_hub-B_Cu.gbl, pppc_usb_hub-B_Mask.gbs, pppc_usb_hub-B_Paste.gbp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]
2024-07-03 Add device settings and enable DMA IRQ
2024-07-11 Add more infomations in README and fix polarity settings
    [main.c]

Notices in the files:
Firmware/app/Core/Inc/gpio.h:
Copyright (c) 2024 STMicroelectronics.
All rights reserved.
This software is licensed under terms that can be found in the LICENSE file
